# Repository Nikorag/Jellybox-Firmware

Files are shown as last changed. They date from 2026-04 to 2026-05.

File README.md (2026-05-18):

# Jellybox Firmware

<p align="center">
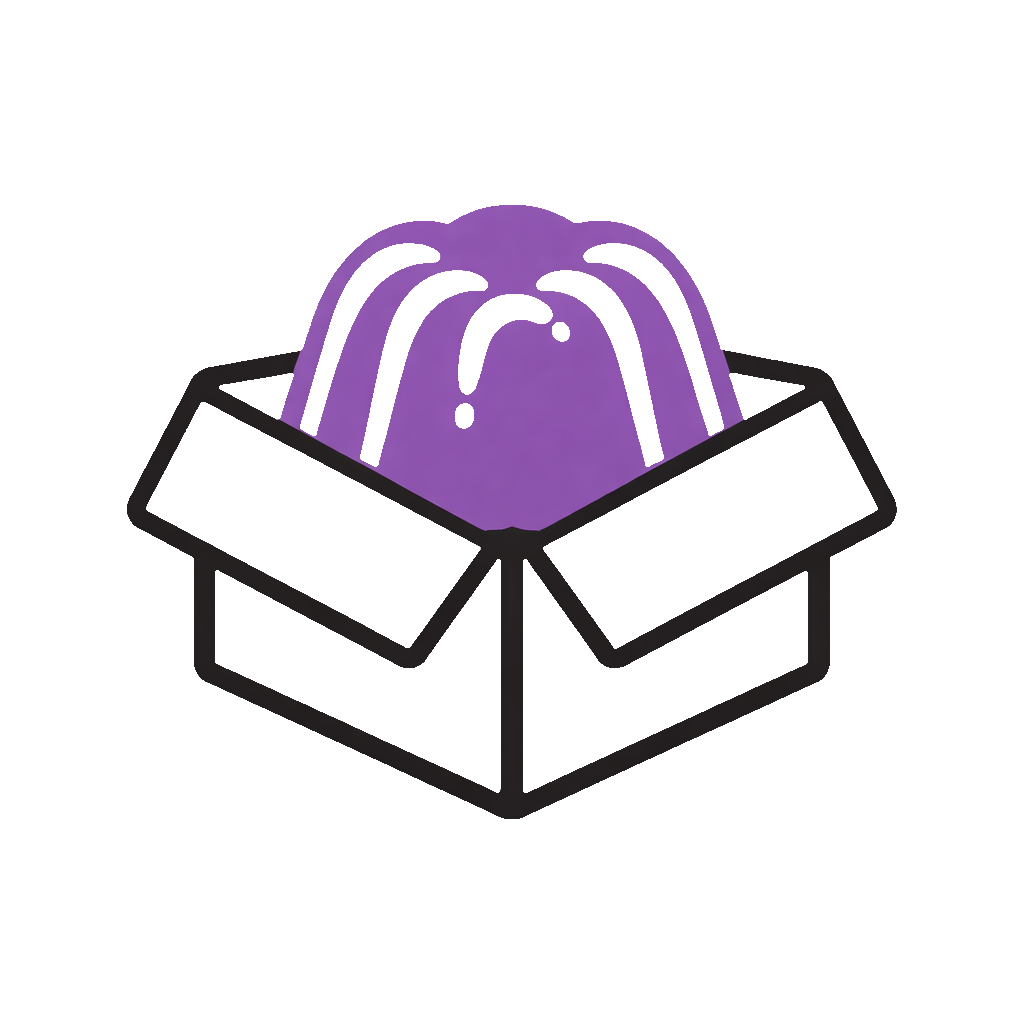
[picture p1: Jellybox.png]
Jellybox
  
</p>

ESP32 firmware for the Jellybox physical media player. Scan an RFID/NFC tag → instant playback on your Jellyfin server. No apps, no menus, no typing.

This firmware talks to a [Jellybox Server](https://github.com/Nikorag/Jellybox-Server) instance. You need a server account and a paired device before the firmware does anything useful.

---

## Hardware

| Component | Part |
|---|---|
| MCU | ESP32 Dev Module (any board with GPIO0 BOOT button) |
| NFC reader | PN532 breakout — I2C mode |
| Display | Waveshare 2.9" V2 B/W eInk (296 × 128) |
| LEDs | WS2812B NeoPixel ring — 16 pixels |
| Power | TP4056 with protection + boost converter (4-pad dual-function module) |
| Power switch | SPDT slide / toggle switch — wired in line between TP4056 `OUT+` and ESP32 `VIN` so the device can be turned off without disconnecting the battery |
| Battery | 18650 Li-Ion cell, 2500–3500 mAh |

See [WIRING.md](WIRING.md) for the full pinout, wiring diagrams, power budget, and component notes.

---

## Required Libraries

Install all of these via **Arduino IDE → Tools → Manage Libraries**:

| Library | Author | Min version |
|---|---|---|
| WiFiManager | tzapu | 2.0.17 |
| Adafruit NeoPixel | Adafruit | 1.12 |
| Adafruit PN532 | Adafruit | 1.3 |
| GxEPD2 | ZinggJM | 1.6 |
| Adafruit GFX Library | Adafruit | 1.11 |
| ArduinoJson | Benoit Blanchon | 7.0+ (uses v7 `JsonDocument` API — v6 needs code changes in `APIClient.h`) |

---

## Building and Flashing

1. Open `jellybox-firmware.ino` in Arduino IDE
2. Set board: **Tools → Board → ESP32 Dev Module**
3. Set partition scheme: **Tools → Partition Scheme → Minimal SPIFFS (1.9MB APP with OTA/190KB SPIFFS)**
   - The default 1.2 MB partition is too small for TLS + all libraries
   - This scheme provides two app partitions, which is required for OTA updates. If you flash with `Huge APP` instead, the device will work but will not be able to auto-update.
4. Select the correct port under **Tools → Port**
5. Click **Upload**

If the IDE shows "Connecting…" and stalls, hold the **BOOT button** on the ESP32 board until the upload begins.

> The TP4056 USB port is for battery charging only — it is not connected to the ESP32's UART. Use the ESP32 dev board's own USB port for flashing and serial monitoring.

---

## First-Time Setup

The pairing wizard in the Jellybox Server dashboard handles everything automatically. In brief:

1. Flash the firmware and power the device
2. The Jellybox splash screen appears, then "Connecting…"
3. The device broadcasts a WiFi AP: **`Jellybox-Setup`** (open, no password)
4. Open the Jellybox Server dashboard → **Devices → Pair New Device**
5. Follow the wizard — it detects the device portal automatically and submits your WiFi credentials, server URL, and API key directly to the device
6. The device reboots, connects to your network, and shows the device name on the eInk display

If you prefer to configure manually:
- Connect to the `Jellybox-Setup` network
- Navigate to `192.168.4.1` (captive portal opens automatically on most phones)
- Enter WiFi credentials, server URL, and API key, then submit

The portal times out after **180 seconds**. If it closes before you finish, the device restarts and broadcasts the AP again.

---

## Factory Reset

Hold the **BOOT button for 3 seconds** at any point while the device is running. The device clears all stored WiFi credentials and server config from NVS, then restarts into setup mode.

You can also trigger a factory reset during power-up: hold BOOT while connecting power.

---

## Over-the-Air Updates

OTA is **user-triggered from the dashboard**, not automatic. Devices never flash themselves the moment a new release lands — you decide when each Jellybox restarts.

**How it works**

1. Each release tag (e.g. `v0.1.0`) triggers the GitHub Actions workflow in `.github/workflows/release.yml`. The workflow builds the firmware with the version baked in (`-DFIRMWARE_VERSION="v0.1.0"`), publishes a release with the `.bin` plus a `manifest.json`.
2. The Jellybox Server fetches that manifest periodically. The device sends its currently-running version on every `GET /api/device/me` poll as a `?version=` query param.
3. The server only includes a `latestFirmware: { version, url }` block in the response **after the user clicks "Update firmware"** in the dashboard, which sets the device's `firmwareUpdatePending` flag.
4. When the device receives that block, it shows the "Updating firmware" screen, downloads the binary directly from GitHub, flashes it, and reboots into the new image.
5. After reboot the device reports the new version on its next poll. The server compares it to the manifest version and clears the pending flag automatically.

**Rollback safety**

Freshly flashed firmware is marked `PENDING_VERIFY` by the bootloader. The new image only commits itself once it has successfully reached the server (`[OTA] Marking current image valid` in the serial log). If the new firmware fails to connect, crashes, or hits a watchdog reset before that point, the bootloader rolls back to the previous working partition automatically. No bricked devices, no manual intervention.

**Local builds never auto-update**

Arduino IDE builds compile with `FIRMWARE_VERSION="dev"`. The OTA check short-circuits on `"dev"`, so a device flashed from your laptop will never overwrite your work-in-progress with a release build.

**Required partition scheme**

OTA needs two app partitions, which is why the build flag `Minimal SPIFFS (1.9MB APP with OTA/190KB SPIFFS)` is mandatory. Devices flashed with `Huge APP` will work but cannot auto-update — they'll need a USB reflash to pick up the OTA-capable partition table.

**Releasing a new version**

```bash
git tag v0.1.0
git push --tags
```

The workflow does the rest. Watch the Actions tab for the build, and the Releases tab for the published artifacts.

---

## LED States

The 16-pixel NeoPixel ring indicates device state at a glance.

| Colour / pattern | Meaning |
|---|---|
| Solid purple | Booting — shown during the blocking WiFi-connect phase in `setup()`, before the cooperative `loop()` takes over |
| Blue breathing | Ready to scan — idle, waiting for a tag |
| Cyan spin (comet) | Connecting — WiFi handshake or HTTP request in progress |
| Yellow spin (comet) | Bootstrapping — contacting the server |
| Purple breathing | Scan-capture mode — the next scan registers a tag, not play |
| Green flash | Success — playback started, or tag captured |
| Red flash | Error — check serial monitor for detail |
| Amber breathing | Unpaired — no config, or API key rejected (401) |
| Solid amber | Setup portal active — waiting for WiFi credentials (`loop()` is blocked, can't animate) |
| Fast white breathing | Charging — battery is charging via USB |
| Slow green breathing | Charged — battery is full |
| Violet spin (comet) | Updating firmware — OTA download in progress |

Charging states only show when the device is idle (READY). Scan-capture mode, errors, and success flashes take priority.

---

## eInk Display Screens

| Screen | When shown |
|---|---|
| Splash (logo + JELLYBOX) | Once at every boot |
| Connecting… | WiFi connecting with no known network |
| Connecting to `<SSID>` | After WiFi connects — shows the network name |
| Unpaired — connect to Jellybox-Setup | No config stored, or API key rejected |
| Logo / `<device name>` | Idle, waiting for a tag (intentionally indistinguishable from power-off — eInk persists) |
| `<device name>` / `[ SCAN MODE ]` | Scan-capture mode active |
| `<device name>` / Now playing: `<title>` | Tag scanned, playback started |
| Error: `<message>` | Something went wrong |
| Updating firmware / `<old> -> <new>` / Do not unplug | OTA update starting |
| Updating firmware / progress bar / `XX%` | OTA download in progress |
| Update failed / `<error>` | OTA download failed — device retries on next bootstrap |

---

## File Structure

| File | Purpose |
|---|---|
| `jellybox-firmware.ino` | `setup()` / `loop()` — state machine, WiFiManager, app entry point |
| `Config.h` | Pin definitions, NVS keys, timing constants |
| `LEDRing.h` | Non-blocking NeoPixel animations (breathing, spin, flash) |
| `EInkDisplay.h` | GxEPD2 screen layouts — all display states in one class |
| `JellyboxLogo.h` | 72×72 px PROGMEM bitmap for the splash / ready screens |
| `NFCReader.h` | PN532 I2C wrapper with UID debounce |
| `APIClient.h` | HTTPS client for `/api/device/me` and `/api/play` |
| `OTAUpdater.h` | OTA firmware download, install, and rollback-commit logic |
| `WIRING.md` | Full hardware wiring guide, pinout, and power budget |
| `.github/workflows/release.yml` | CI that builds firmware on `v*` tags and publishes a manifest for OTA |

---

## State Machine

```
                       ┌─────────────┐
          power on     │ UNCONFIGURED│ ◄── 401 from server
         ─────────────►│             │
                       └──────┬──────┘
                              │ WiFi + config saved
                              ▼
                       ┌─────────────┐
                       │ CONNECTING  │ WiFiManager autoConnect
                       └──────┬──────┘
                              │ connected
                              ▼
                       ┌──────────────┐
             ┌────────►│ BOOTSTRAPPING│ GET /api/device/me (every 30 s)
             │         └──────┬───────┘
             │                │ ok
             │       ┌────────┴────────┐
             │       │                 │
             │       ▼                 ▼
             │  ┌─────────┐     ┌───────────┐
             │  │  READY  │     │ SCAN_MODE │
             │  └────┬────┘     └─────┬─────┘
             │       │ NFC scan        │ NFC scan
             │       └────────┬────────┘
             │                │ POST /api/play
             └────────────────┘ (re-bootstrap every 30 s)

   BOOTSTRAPPING ──► UPDATING ──► reboot into new firmware
                       │ (only if latestFirmware.version != FIRMWARE_VERSION)
                       └► back to BOOTSTRAPPING on download failure
```

---

## API Interactions

The firmware makes two HTTPS calls to the server:

**`GET /api/device/me`** — called at boot and every 30 seconds  
Authenticated with `Authorization: Bearer <apiKey>`. Returns:
```json
{
  "name": "Living Room Box",
  "scanMode": false,
  "latestFirmware": {
    "version": "v0.1.0",
    "url": "https://github.com/.../jellybox-firmware-v0.1.0.bin"
  }
}
```
A `401` response sets the device to UNPAIRED state. Other errors are retried on the next interval. The `latestFirmware` block is only present when the user has flagged the device for an update in the dashboard — otherwise it's omitted and the firmware treats that as "no update available". See the [OTA section](#over-the-air-updates) for the full update flow.

**`POST /api/play`** — called when a tag is scanned  
```json
{ "tagId": "A1B2C3D4" }
```
Returns either:
```json
{ "success": true, "content": "The Dark Knight" }
{ "captured": true }
{ "error": "Tag not assigned" }
```

TLS certificates are not verified on-device (`setInsecure()`). The API key is the shared secret; verifying the server cert would require bundling a CA store, which is impractical for a battery-powered device pointing at a self-hosted server.

---

## Customisation

### Changing the eInk panel

Edit the top of `EInkDisplay.h`. The include and class alias are the only two lines to change:

```cpp
// Example: Waveshare 2.13" V3 (250×122)
#include <epd/GxEPD2_213_BN.h>
using Panel = GxEPD2_BW<GxEPD2_213_BN, GxEPD2_213_BN::HEIGHT>;
```

Adjust `EINK_W`, `EINK_H`, and `EINK_MARGIN_R` to match the new panel's pixel dimensions and dead zone.

### Changing the NeoPixel count or pin

Edit `Config.h`:
```cpp
#define PIN_NEOPIXEL   27
#define NEOPIXEL_COUNT 16
```

### Adjusting poll intervals

Also in `Config.h`:
```cpp
#define BOOTSTRAP_INTERVAL_MS  30000UL  // server poll — every 30 s
#define SCAN_DEBOUNCE_MS        3000UL  // ignore same UID for 3 s
#define FACTORY_RESET_HOLD_MS   3000UL  // hold BOOT 3 s to reset
```

---

## Stored Configuration (NVS)

Config is stored in the ESP32's Non-Volatile Storage under the `jellybox` namespace. The partition scheme change (`Minimal SPIFFS`) does not affect NVS — it is a separate partition and survives reflashing.

| Key | Value |
|---|---|
| `serverUrl` | Full server URL, e.g. `https://jellybox.example.com` |
| `apiKey` | Device API key, e.g. `jb_abc123…` |

WiFi credentials are stored separately by the ESP32 WiFi stack and erased by `WiFi.disconnect(true, true)` during a factory reset.

---

## Serial Monitor

Connect at **115200 baud**. All state transitions, NFC scans, API calls, and errors are logged with prefixed tags:

```
[NFC]    Tag: A1B2C3D4
[API]    POST /api/play → 200
[Play]   Playing: The Dark Knight
[Boot]   Device: Living Room Box scanMode=0
[Charge] charging
[Reset]  BOOT held...
[OTA]    Update available: v0.0.3 -> v0.1.0
[OTA]    Marking current image valid (was pending verify)
```

The boot banner also reports the running firmware version, e.g. `=== Jellybox starting (firmware v0.1.0) ===` (or `firmware dev` for local builds).

---

## License

MIT

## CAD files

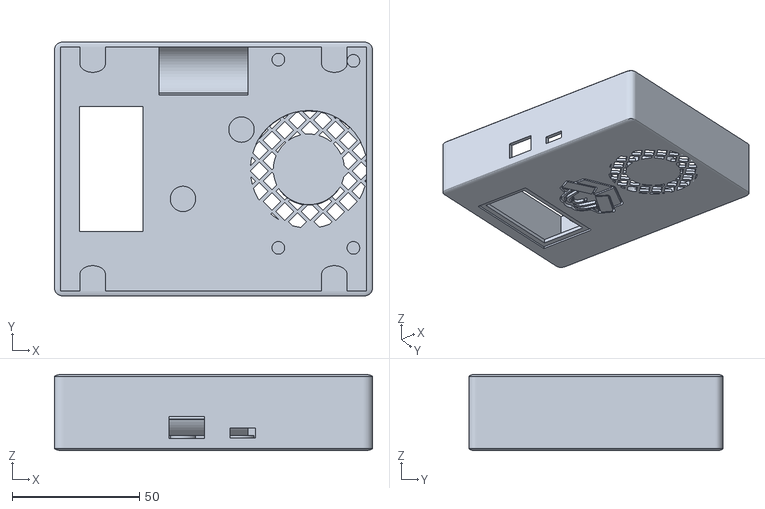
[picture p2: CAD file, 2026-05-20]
models/Jellybox Case.stl
125.0 x 100.0 x 30.0

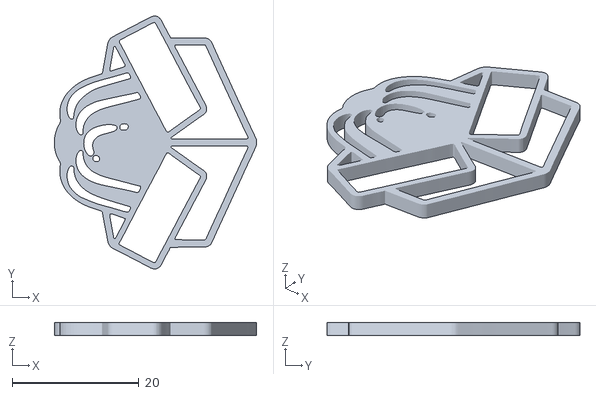
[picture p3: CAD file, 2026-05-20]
models/Jellybox Logo.stl
32.0 x 40.0 x 2.00

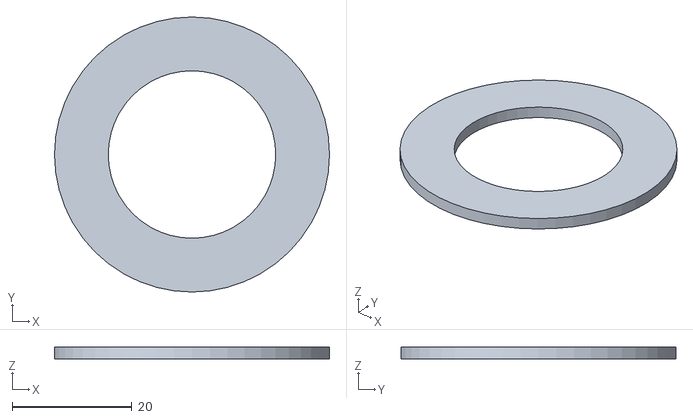
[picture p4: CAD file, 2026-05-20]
models/Jellybox Ring.stl
46.0 x 46.0 x 2.00

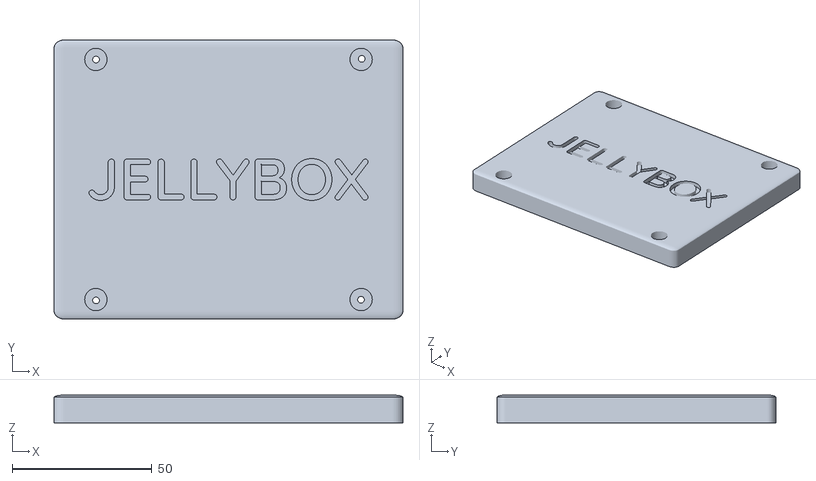
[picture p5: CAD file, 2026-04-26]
models/Jellybox Lid.stl
125.0 x 100.0 x 10.00

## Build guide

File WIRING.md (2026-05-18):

# Jellybox Hardware Wiring

Hardware reference for assembling a Jellybox device.
Signal logic runs at **3.3 V**. The TP4056 module provides a regulated **5 V** rail that
powers everything; the ESP32's onboard LDO steps that down to 3.3 V for the PN532 and eInk.

---

## Components

| Component | Part |
|---|---|
| MCU | ESP32 Dev Module (any board with GPIO0 BOOT button) |
| Power | 5 V / 1 A TP4056 with protection + boost converter (dual-function, 4-pad module) |
| Power switch | SPDT slide or toggle switch (any small switch rated ≥ 1 A) |
| Battery | 18650 Li-Ion cell — see battery selection note below |
| NFC reader | PN532 breakout (I2C mode) |
| Display | Waveshare 2.9" V2 B/W eInk (296 × 128) |
| LEDs | WS2812B NeoPixel ring — 16 pixels |
| Reset button | On-board BOOT button (GPIO0) |

---

## Battery Selection

Any genuine 18650 Li-Ion cell. The TP4056 charges at ~1 A, so aim for at least 1500 mAh
(keeping charge rate ≤ 0.66 C). A **2500–3500 mAh** cell is ideal.

| Cell | Capacity | Notes |
|---|---|---|
| Samsung 25R | 2500 mAh | Widely available, reliable |
| LG HG2 | 3000 mAh | Good capacity/current balance |
| Molicel P26A | 2600 mAh | Excellent quality |

Buy from a reputable supplier. Avoid unbranded cells claiming ≥ 5000 mAh — 18650 cells
physically cannot hold more than ~3600 mAh; anything higher is a false rating.

**Estimated runtime** at typical idle (WiFi connected, LED breathing, no active scans):
~120–150 mA average draw → **16–23 hours** from a 2500 mAh cell.

---

## Pin Assignment

| Signal | ESP32 GPIO | Connected to |
|---|---|---|
| I2C SDA | 21 (default) | PN532 SDA |
| I2C SCL | 22 (default) | PN532 SCL |
| PN532 IRQ | 25 | PN532 IRQ |
| PN532 RST | 26 | PN532 RST / RSTO |
| SPI MOSI | 23 (VSPI default) | eInk DIN |
| SPI SCK | 18 (VSPI default) | eInk CLK |
| eInk CS | 5¹ | eInk CS |
| eInk DC | 17 | eInk DC |
| eInk RST | 16 | eInk RST |
| eInk BUSY | 4 | eInk BUSY |
| NeoPixel DATA | 27 | Ring DATA IN (via 470 Ω) |
| TP4056 CHRG | 32 | Red LED cathode on TP4056 module |
| TP4056 STDBY | 33 | Blue LED cathode on TP4056 module |
| Factory reset | 0 | BOOT button (on-board) |

> ¹ GPIO5 is an ESP32 boot-mode strapping pin. The eInk CS line idles HIGH (SPI CS is
> active-low), so it does not affect boot behaviour. If you ever see unexpected boot
> failures, probe GPIO5 at power-on.

---

## 1 — TP4056 Power Module

The module has **4 solder pads** and a single USB port (charging input):

| Pad label | Purpose |
|---|---|
| `OUT+` | 5 V regulated output — connect to ESP32 VIN and NeoPixel PWR |
| `OUT−` | GND — connect to common ground |
| `B+` | Battery positive — connect to 18650 cell + terminal |
| `B−` | Battery negative — connect to 18650 cell − terminal |

```
USB (wall/PC)
     │
 [TP4056 module]
  ┌──┴────────────────┐
  │  B+  ←→  18650 +  │
  │  B−  ←→  18650 −  │
  │                   │
  │  OUT+ ──→ [SPDT switch] ──→ 5V rail (ESP32 VIN, NeoPixel PWR)
  │  OUT− ──────────────────────→ GND
  └───────────────────┘
```

**Power switch:** wire an **SPDT slide or toggle switch** in series between TP4056 `OUT+` and
the ESP32 `VIN` pin (the same node that feeds NeoPixel `PWR`). Flipping the switch off
completely disconnects the 5 V rail so the device draws no power from the cell — the only
correct way to "turn the Jellybox off" between uses, since the firmware has no sleep mode yet.

> **Switch the OUT+ side, not B+.** Wiring the switch between the cell and the TP4056 input
> would also disconnect the charger, meaning the device couldn't charge over USB while
> switched off. With the switch on `OUT+`, USB charging still works with the device powered
> down.

**Simultaneous charge and run:** this module supports pass-through — when the switch is on,
the device can run from the 5 V output while USB is connected and the battery is charging.

**Current headroom:** total worst-case draw is ~470 mA (see power budget below). The module is
rated 1 A output, leaving ~530 mA headroom. Simultaneous WiFi TX + NFC field + full LED is
unlikely in practice; average draw in normal use is well under 200 mA.

---

## 2 — TP4056 Charging Indicator (optional)

The firmware uses the NeoPixel ring to indicate charge state. This requires tapping the
TP4056's two status outputs: `CHRG` (active while charging) and `STDBY` (active when full).
Both are open-drain, active-LOW signals.

### Where to solder

Your module has two small indicator LEDs on the PCB (typically red = charging, blue = full).
Solder fine wire to the **cathode** of each LED — that pad connects directly to the TP4056
status pin. The cathode is the shorter leg, or the leg on the flat/marked side of the LED.

Use a fine-tipped iron and thin wire (~28 AWG). The pads are small; work quickly to avoid
lifting them.

```
TP4056 module (LED cathode pads)    ESP32
────────────────────────────────────────────
Red LED cathode  (CHRG)   →   GPIO 32   (INPUT_PULLUP)
Blue LED cathode (STDBY)  →   GPIO 33   (INPUT_PULLUP)
```

### Why no voltage divider is needed

The ESP32's internal pull-up (45 kΩ to 3.3 V) clamps the floating-high state to 3.3 V.
The on-board LED's series resistor (~1 kΩ) + forward voltage (~2 V) prevents the 5 V rail
from forward-biasing the LED in the direction of the GPIO, so no 5 V reaches the pin.
When the TP4056 pulls the output LOW, the GPIO reads 0 V regardless of the pull-up.

### LED behaviour

| Ring animation | Meaning |
|---|---|
| Fast white breathing (~2.4 s) | Battery charging |
| Slow green breathing (~6 s) | Battery full |
| Blue breathing (normal IDLE) | On battery, not connected to charger |

Charging states only show when the device is in READY state. SCAN_MODE, UNPAIRED, and
transient flashes (SUCCESS / ERROR) take priority.

---

## 3 — PN532 NFC Reader (I2C)

### Set I2C mode first

The PN532 supports I2C, SPI, and UART. **You must select I2C before wiring.**

- **Adafruit breakout:** flip the two DIP switches — `SW1 = ON`, `SW2 = OFF`
- **Other breakouts:** consult the board's datasheet for the I2C solder-jumper or switch positions

### Connections

```
PN532 breakout       ESP32
──────────────────────────────
VCC           →   3.3V
GND           →   GND
SDA           →   GPIO 21
SCL           →   GPIO 22
IRQ           →   GPIO 25
RST (RSTO)    →   GPIO 26
```

> **VCC note:** connect to the ESP32's 3V3 pin. Most PN532 breakout boards accept 3.3 V directly
> on their logic/VCC pin and run reliably at that voltage.

### Pull-ups

The Adafruit PN532 breakout includes on-board 4.7 kΩ pull-ups on SDA and SCL — no external
resistors needed. If using a bare PN532 module without on-board pull-ups, add 4.7 kΩ resistors
from SDA → 3.3 V and SCL → 3.3 V.

---

## 4 — Waveshare 2.9" V2 eInk Display (SPI)

Pin labels vary by module revision. Common label sets and their mappings:

| Signal | Variant A labels | Variant B labels |
|---|---|---|
| Power | VCC | VCC |
| Ground | GND | GND |
| Data (MOSI) | DIN | SDA |
| Clock (SCK) | CLK | SCL |
| Chip select | CS | CS |
| Data/command | DC | DC |
| Reset | RST | RES |
| Busy | BUSY | BUSY |

MISO is not connected — the panel is write-only.

```
Your module    Signal        ESP32
──────────────────────────────────
VCC        →  3.3V
GND        →  GND
SDA / DIN  →  GPIO 23   (MOSI)
SCL / CLK  →  GPIO 18   (SCK)
CS         →  GPIO  5
DC         →  GPIO 17
RES / RST  →  GPIO 16
BUSY       →  GPIO  4
```

GxEPD2 initialises the SPI bus internally — no `SPI.begin()` call is needed in the sketch.

---

## 5 — WS2812B NeoPixel Ring (16 pixels)

```
NeoPixel ring        Power / ESP32
────────────────────────────────────
PWR (5V)      →   TP4056 OUT+  (5 V rail — not the ESP32 5V pin)
GND           →   GND
DATA IN       →   GPIO 27  (via 300–470 Ω series resistor)
```

**Why TP4056 OUT+ directly?** The ESP32 dev board's 5 V / VBUS pin is only live when USB is
connected. When running on battery alone that pin is dead. Tapping the 5 V rail from the
TP4056 output ensures the ring is powered in both USB and battery modes.

**Series resistor:** place a 300–470 Ω resistor on the data line between GPIO27 and the
ring's DATA IN pad. It suppresses ringing and protects the first pixel's input driver.

---

## 6 — Factory Reset Button

The BOOT button is already wired to GPIO0 on most ESP32 dev boards with an on-board pull-up.
No additional wiring is needed.

If building a custom PCB, wire a momentary pushbutton between GPIO0 and GND. The firmware
configures `INPUT_PULLUP` in software, so no external pull-up is required.

**To factory reset:** hold the BOOT button for 3 seconds on power-up. The device clears its
NVS config and stored WiFi credentials, then restarts into setup mode.

---

## 7 — Power Budget

| Subsystem | Typical draw |
|---|---|
| ESP32 active + WiFi TX | ~200 mA peak |
| WS2812B ring (brightness 80/255) | ~150 mA |
| PN532 during RF field | ~100 mA peak |
| eInk during refresh | ~20 mA |
| **Total worst-case** | **~470 mA** |
| **TP4056 output rating** | **1000 mA** |
| **Headroom** | **~530 mA** |

All peaks are brief and non-overlapping in normal use. Average idle draw (WiFi connected,
LED breathing, waiting for a scan) is approximately **120–150 mA**.

The TP4056 module's onboard LDO is not in this path — the boost converter output feeds
ESP32 VIN directly. The ESP32's onboard AMS1117 (3.3 V, 800 mA) is fed clean 5 V and
supplies the PN532 and eInk from its 3V3 pin.

---

## 8 — Full Wiring Diagram

```
  [USB charger]                    [18650 cell]
       │                            │       │
       │          ┌─────────────────┤ B+  B−├──┐
       └──────────┤ USB    TP4056              │ │
                  │  5V boost module           │ │
                  │         OUT+ ──[SPDT sw]───┼─┼──── 5V rail
                  │         OUT− ──────────────┼─┼──── GND rail
                  └────────────────────────────┘ │
                                                  │ (battery ground)
                                                  ▼

  5V rail ────────────────────────────────────────────────┐
                                                          │
                 ┌──────────────────────────────────────┐ │
    NeoPixel PWR─┤ VIN (→ AMS1117 → 3V3)               │ │
                 │                                       │ │
 [NeoPixel]──470Ω│ GPIO27              GPIO21 ───────────│─┼── SDA ──[PN532]
 [eInk RES/RST]──│ GPIO16              GPIO22 ───────────│─┼── SCL ──[PN532]
 [eInk DC]───────│ GPIO17              GPIO25 ───────────│─┼── IRQ ──[PN532]
 [eInk BUSY]─────│ GPIO 4              GPIO26 ───────────│─┼── RST ──[PN532]
 [eInk CS]───────│ GPIO 5                                │ │
 [eInk SCL/SCK]──│ GPIO18              GPIO 0 ───────────│─┼── BOOT button
 [eInk SDA/DIN]──│ GPIO23                                │ │
                 │                          3V3 ─────────│─┼── PN532 VCC
                 │                          3V3 ─────────│─┼── eInk VCC
                 │                          GND ─────────│─┼── all GND
                 └──────────────────────────────────────┘ │
                                                          │
  GND rail ────────────────────────────────────────────── ┘
```

---

## 9 — First Boot

1. Flash the firmware via Arduino IDE (**Board: ESP32 Dev Module**) with USB connected
2. Disconnect USB. The device now runs from the battery (LED will light)
3. On first boot it broadcasts a WiFi AP: **`Jellybox-Setup`** (open, no password)
4. Connect to it — a captive portal opens automatically (or navigate to `192.168.4.1`)
5. Enter your WiFi credentials, the server URL, and the device API key from the dashboard
6. Submit — the device reboots, connects, and shows the device name on the eInk display

If the portal times out (180 s default) without a submission, the device restarts and
broadcasts the AP again.

> **Flashing note:** flashing via Arduino IDE requires USB. The TP4056's USB port is for
> charging only — it is not connected to the ESP32's USB/UART. Use the ESP32 dev board's own
> USB port for flashing and serial monitoring.

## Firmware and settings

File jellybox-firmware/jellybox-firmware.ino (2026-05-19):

/**
 * Jellybox Firmware
 *
 * ESP32 companion device for the Jellybox Server SaaS.
 * Scans RFID/NFC tags → POST /api/play → Jellyfin playback.
 *
 * Required Arduino libraries (install via Library Manager):
 *   - WiFiManager         by tzapu          (v2.0.17+)
 *   - Adafruit NeoPixel   by Adafruit       (v1.12+)
 *   - Adafruit PN532      by Adafruit       (v1.3+)
 *   - GxEPD2              by ZinggJM        (v1.6+)
 *   - Adafruit GFX Library by Adafruit      (v1.11+)
 *   - ArduinoJson         by Benoit Blanchon (v7+ or v6 — see APIClient.h)
 *
 * Board: ESP32 Dev Module (Arduino ESP32 core v2.x or v3.x)
 */

#include <WiFi.h>
#include <WiFiManager.h>
#include <Preferences.h>

#include "Config.h"
#include "LEDRing.h"
#ifdef JELLYBOX_DISPLAY_TFT
  #include "TFTDisplay.h"
#else
  #include "EInkDisplay.h"
#endif
#include "NFCReader.h"
#include "APIClient.h"
#include "OTAUpdater.h"
#include "UDPLogger.h"
#ifdef JELLYBOX_HAS_AUDIO
  #include "AudioFeedback.h"
#endif
#ifdef JELLYBOX_HAS_VOLUME_DIAL
  #include "VolumeControl.h"
#endif

LEDRing     led;
#ifdef JELLYBOX_DISPLAY_TFT
TFTDisplay  eink;   // variable name unchanged so existing call sites work as-is
#else
EInkDisplay eink;
#endif
NFCReader   nfc;
APIClient   api;
UDPLogger   ulog;
Preferences prefs;
#ifdef JELLYBOX_HAS_AUDIO
AudioFeedback audio;
#endif
#ifdef JELLYBOX_HAS_VOLUME_DIAL
VolumeControl volume;
#endif

// Returns the current audio gain (0.0–1.0). Uses the volume dial when
// compiled in, otherwise a sensible fixed level so the speaker isn't
// deafening on boards without a dial.
static inline float audioGain() {
#ifdef JELLYBOX_HAS_VOLUME_DIAL
  return volume.gain();
#else
  return 0.6f;
#endif
}

DeviceConfig cfg;

// Diagnostic state for the UDP heartbeat. Tracks NFC liveness from the
// main loop's perspective — readUID() returning "" looks the same whether
// the PN532 is dead, the I2C bus is stuck, or there genuinely isn't a tag.
unsigned long lastHeartbeat       = 0;
unsigned long emptyReadsInWindow  = 0;
unsigned long lastSuccessfulRead  = 0;
String        lastSuccessfulUID   = "";

enum class AppState {
  UNCONFIGURED,
  CONNECTING,
  BOOTSTRAPPING,
  READY,
  SCAN_MODE,
  UPDATING,
};
AppState appState = AppState::UNCONFIGURED;

String        deviceName   = "";
bool          nfcReady     = false;
unsigned long lastBootstrap = 0;

unsigned long bootBtnStart = 0;
bool          bootBtnHeld  = false;

WiFiManagerParameter* wm_serverUrl = nullptr;
WiFiManagerParameter* wm_apiKey    = nullptr;

void loadConfig() {
  prefs.begin(NVS_NAMESPACE, true);
  cfg.serverUrl = prefs.getString(NVS_KEY_SERVER, "");
  cfg.apiKey    = prefs.getString(NVS_KEY_APIKEY,  "");
  prefs.end();
  if (cfg.serverUrl.endsWith("/"))
    cfg.serverUrl = cfg.serverUrl.substring(0, cfg.serverUrl.length() - 1);
}

void saveConfig(const String& serverUrl, const String& apiKey) {
  String su = serverUrl;
  if (su.endsWith("/")) su = su.substring(0, su.length() - 1);
  prefs.begin(NVS_NAMESPACE, false);
  prefs.putString(NVS_KEY_SERVER, su);
  prefs.putString(NVS_KEY_APIKEY,  apiKey);
  prefs.end();
  Serial.println("[Config] Saved — server: " + su);
}

void factoryReset() {
  Serial.println("[Config] Factory reset!");
  prefs.begin(NVS_NAMESPACE, false);
  prefs.clear();
  prefs.end();
  WiFi.disconnect(true, true);
  delay(300);
  ESP.restart();
}

void onPortalSave() {
  if (!wm_serverUrl || !wm_apiKey) return;
  String su = String(wm_serverUrl->getValue());
  String ak = String(wm_apiKey->getValue());
  su.trim(); ak.trim();
  saveConfig(su, ak);
  cfg.serverUrl = su;
  cfg.apiKey    = ak;
}

void startWiFi(bool forcePortal) {
  WiFiManager wm;
  wm.setConnectTimeout(20);
  wm.setConfigPortalTimeout(WIFI_TIMEOUT_S);
  wm.setSaveParamsCallback(onPortalSave);
  wm.setTitle("Jellybox Setup");
  wm.setShowInfoUpdate(false);
  wm_serverUrl = new WiFiManagerParameter("server", "Server URL", cfg.serverUrl.c_str(), 128, " placeholder=\"https://jellybox.example.com\"");
  wm_apiKey    = new WiFiManagerParameter("apikey",  "API Key",    cfg.apiKey.c_str(),    80,  " placeholder=\"jb_...\"");
  wm.addParameter(wm_serverUrl);
  wm.addParameter(wm_apiKey);
  wm.setWebServerCallback([&]() {
    wm.server->on("/hotspot-detect.html", HTTP_GET, [&]() {
      wm.server->send(200, "text/html", "<HTML><HEAD><TITLE>Success</TITLE></HEAD><BODY>Success</BODY></HTML>");
    });
    wm.server->on("/generate_204", HTTP_GET, [&]() {
      wm.server->send(204, "text/plain", "");
    });
  });
  bool connected = forcePortal
    ? (eink.showUnpaired(), led.setState(LEDState::SETUP_PORTAL), led.setBaseState(LEDState::UNPAIRED), led.update(), wm.startConfigPortal(WIFI_AP_NAME, WIFI_AP_PASSWORD))
    : wm.autoConnect(WIFI_AP_NAME, WIFI_AP_PASSWORD);
  delete wm_serverUrl; wm_serverUrl = nullptr;
  delete wm_apiKey;    wm_apiKey    = nullptr;
  if (!connected) { Serial.println("[WiFi] Failed — restarting"); delay(500); ESP.restart(); }
  eink.showConnecting(WiFi.SSID());
  Serial.println("[WiFi] Connected to " + WiFi.SSID() + " — IP: " + WiFi.localIP().toString());
}

void doBootstrap() {
  unsigned long t0 = millis();
  ulog.logf("BOOT bootstrap_start heap=%u maxAlloc=%u",
    (unsigned)ESP.getFreeHeap(), (unsigned)ESP.getMaxAllocHeap());
  led.setState(LEDState::BOOTSTRAPPING);
  led.setBaseState(LEDState::BOOTSTRAPPING);
  api.configure(cfg.serverUrl, cfg.apiKey);
  BootstrapResult res = api.bootstrap();
  lastBootstrap = millis();
  if (!res.ok) {
    ulog.logf("BOOT bootstrap_fail http=%d took=%lums heap=%u",
      res.httpCode, millis() - t0, (unsigned)ESP.getFreeHeap());
    if (res.httpCode == 401) {
      Serial.println("[Boot] 401 — invalid API key");
      eink.showUnpaired(); led.setState(LEDState::ERROR); led.setBaseState(LEDState::UNPAIRED);
      appState = AppState::UNCONFIGURED;
    } else {
      Serial.printf("[Boot] Error HTTP %d — retrying later\n", res.httpCode);
      if (WiFi.status() != WL_CONNECTED) WiFi.reconnect();
      led.setState(LEDState::ERROR); led.setBaseState(LEDState::IDLE);
      if (deviceName.isEmpty()) eink.showConnecting();
      appState = AppState::READY;
    }
    return;
  }
  deviceName = res.name;
  Serial.println("[Boot] Device: " + deviceName + " scanMode=" + String(res.scanMode));

  // First successful bootstrap proves the running firmware can talk to the
  // network and the server — commit the partition so the bootloader doesn't
  // roll it back on next reset. No-op on subsequent boots.
  static bool firstBootstrapDone = false;
  if (!firstBootstrapDone) {
    firstBootstrapDone = true;
    OTAUpdater::markCurrentAppValid();
  }

  // Server-driven OTA. If an update is available, this either reboots into
  // the new firmware (success) or falls through and we resume normal flow
  // — the same update will be retried on the next bootstrap.
  if (OTAUpdater::isUpdateAvailable(res.latestFirmwareVersion)) {
    Serial.printf("[OTA] Update available: %s -> %s\n",
      FIRMWARE_VERSION, res.latestFirmwareVersion.c_str());
    appState = AppState::UPDATING;
    led.setState(LEDState::UPDATING);
    led.setBaseState(LEDState::UPDATING);
    eink.showUpdating(FIRMWARE_VERSION, res.latestFirmwareVersion);
    if (!OTAUpdater::performUpdate(res.latestFirmwareUrl)) {
      eink.showUpdateFailed("Update failed - will retry");
      unsigned long wait = millis();
      while (millis() - wait < 3000) { led.update(); checkFactoryReset(); delay(10); }
    }
    // On success the device has rebooted and we never get here.
  }

  if (res.scanMode) {
    appState = AppState::SCAN_MODE;
    led.setBaseState(LEDState::SCAN_MODE); led.setState(LEDState::SCAN_MODE);
    eink.showScanMode(deviceName);
  } else {
    appState = AppState::READY;
    led.setBaseState(LEDState::IDLE); led.setState(LEDState::IDLE);
    eink.showReady(deviceName);
  }
  // HTTPS handshake + eInk full-window refresh can wedge the PN532's
  // passive-target state machine while leaving I2C alive — re-arm before
  // returning so the next readUID() actually detects tags.
  if (nfcReady) nfc.rearm();
  ulog.logf("BOOT bootstrap_ok scanMode=%d took=%lums heap=%u maxAlloc=%u pn532=0x%08x",
    (int)res.scanMode, millis() - t0,
    (unsigned)ESP.getFreeHeap(), (unsigned)ESP.getMaxAllocHeap(),
    (unsigned)(nfcReady ? nfc.firmwareVersion() : 0));
}

void handleScan(const String& uid) {
  unsigned long t0 = millis();
  ulog.logf("SCAN start uid=%s heap=%u", uid.c_str(), (unsigned)ESP.getFreeHeap());
  led.setState(LEDState::CONNECTING); led.update();
  PlayResult res = api.play(uid);
  if (res.ok) {
    led.setState(LEDState::SUCCESS);
    if (res.captured) {
      Serial.println("[Play] Tag captured: " + uid);
      eink.showReady(deviceName); lastBootstrap = 0;
#ifdef JELLYBOX_HAS_AUDIO
      audio.playImported(audioGain());
#endif
    } else {
      Serial.println("[Play] Playing: " + res.content);
      eink.showLastPlayed(deviceName, res.content);
#ifdef JELLYBOX_HAS_AUDIO
      audio.playSuccess(audioGain());
#endif
    }
  } else {
    Serial.println("[Play] Error: " + res.error);
    led.setState(LEDState::ERROR);
    eink.showError(res.error.isEmpty() ? "Play failed" : res.error);
#ifdef JELLYBOX_HAS_AUDIO
    audio.playError(audioGain());
#endif
    unsigned long wait = millis();
    while (millis() - wait < 3000) { led.update(); checkFactoryReset(); delay(10); }
    appState == AppState::SCAN_MODE ? eink.showScanMode(deviceName) : eink.showReady(deviceName);
  }
  ulog.logf("SCAN end ok=%d captured=%d http=%d content='%s' err='%s' took=%lums heap=%u",
    (int)res.ok, (int)res.captured, res.httpCode,
    res.content.c_str(), res.error.c_str(), millis() - t0,
    (unsigned)ESP.getFreeHeap());
}

void checkFactoryReset() {
  if (digitalRead(PIN_FACTORY_RESET) == LOW) {
    if (!bootBtnHeld) { bootBtnHeld = true; bootBtnStart = millis(); Serial.println("[Reset] BOOT held..."); }
    else if (millis() - bootBtnStart > FACTORY_RESET_HOLD_MS) {
      led.setState(LEDState::ERROR); led.update(); eink.showUnpaired(); factoryReset();
    }
  } else { bootBtnHeld = false; }
}

void setup() {
  Serial.begin(115200); delay(100);
  Serial.printf("\n\n=== Jellybox starting %s ===\n", FIRMWARE_VERSION);
  pinMode(PIN_FACTORY_RESET, INPUT_PULLUP);
  led.begin(); led.setState(LEDState::BOOTING); led.update();
#ifdef JELLYBOX_DISPLAY_EINK
  // Pre-set eInk control pins as outputs at idle level so GxEPD2's init()
  // doesn't trip the "digitalWrite before pinMode" warning on ESP32 core 3.x.
  pinMode(PIN_EINK_CS,  OUTPUT); digitalWrite(PIN_EINK_CS,  HIGH);
  pinMode(PIN_EINK_DC,  OUTPUT); digitalWrite(PIN_EINK_DC,  HIGH);
  pinMode(PIN_EINK_RST, OUTPUT); digitalWrite(PIN_EINK_RST, HIGH);
#endif
#ifdef JELLYBOX_DISPLAY_TFT
  pinMode(PIN_TFT_CS,  OUTPUT); digitalWrite(PIN_TFT_CS,  HIGH);
  pinMode(PIN_TFT_DC,  OUTPUT); digitalWrite(PIN_TFT_DC,  HIGH);
  pinMode(PIN_TFT_RST, OUTPUT); digitalWrite(PIN_TFT_RST, HIGH);
#endif
  eink.begin(); eink.showSplash(); eink.showConnecting();
#ifdef JELLYBOX_HAS_VOLUME_DIAL
  volume.begin();
#endif
  loadConfig();
  { unsigned long h = millis();
    while (digitalRead(PIN_FACTORY_RESET) == LOW) {
      led.update();
      if (millis() - h > FACTORY_RESET_HOLD_MS) { Serial.println("[Reset] Factory reset on boot"); led.setState(LEDState::ERROR); led.update(); eink.showUnpaired(); factoryReset(); }
      delay(10);
    }
  }
  nfcReady = nfc.begin();
  if (!nfcReady) Serial.println("[NFC] Reader not found — NFC disabled");
  bool needPortal = cfg.serverUrl.isEmpty() || cfg.apiKey.isEmpty();
  startWiFi(needPortal);
  ulog.begin(UDP_LOG_HOST, UDP_LOG_PORT);
#ifdef JELLYBOX_HAS_AUDIO
  audio.begin();
#endif
  ulog.logf("BOOT fw=%s ip=%s ssid=%s heap=%u nfc=%d pn532=0x%08x",
    FIRMWARE_VERSION, WiFi.localIP().toString().c_str(),
    WiFi.SSID().c_str(), (unsigned)ESP.getFreeHeap(),
    (int)nfcReady, (unsigned)(nfcReady ? nfc.firmwareVersion() : 0));
  loadConfig();
  if (cfg.serverUrl.isEmpty() || cfg.apiKey.isEmpty()) {
    Serial.println("[Config] Incomplete — waiting for reset");
    eink.showUnpaired(); led.setBaseState(LEDState::UNPAIRED); led.setState(LEDState::UNPAIRED);
    while (true) { led.update(); checkFactoryReset(); delay(10); }
  }
  doBootstrap();
}

void loop() {
  checkFactoryReset();
  led.update();
#ifdef JELLYBOX_HAS_VOLUME_DIAL
  volume.update();
#endif
  if (millis() - lastBootstrap > BOOTSTRAP_INTERVAL_MS) { doBootstrap(); return; }
  if (nfcReady && (appState == AppState::READY || appState == AppState::SCAN_MODE)) {
    String uid = nfc.readUID();
    if (uid.length() > 0) {
      lastSuccessfulRead = millis();
      lastSuccessfulUID  = uid;
      handleScan(uid);
      // handleScan ran HTTPS + 1–2 eInk full refreshes; same wedge risk
      // as doBootstrap, same fix.
      nfc.rearm();
    } else {
      emptyReadsInWindow++;
    }
  }

  // pn532 firmware-version probe distinguishes "I2C/chip dead" from
  // "chip alive, RF detection broken" — same UDP packet either way.
  if (millis() - lastHeartbeat > HEARTBEAT_INTERVAL_MS) {
    lastHeartbeat = millis();
    uint32_t fw = nfcReady ? nfc.firmwareVersion() : 0;
    unsigned long ageS = (lastSuccessfulRead == 0)
      ? 0 : (millis() - lastSuccessfulRead) / 1000;
    ulog.logf("HB state=%d heap=%u maxAlloc=%u empty=%lu lastUID=%s ageS=%lu pn532=0x%08x wifi=%d",
      (int)appState, (unsigned)ESP.getFreeHeap(), (unsigned)ESP.getMaxAllocHeap(),
      emptyReadsInWindow,
      lastSuccessfulUID.length() ? lastSuccessfulUID.c_str() : "-",
      ageS, (unsigned)fw, (int)WiFi.status());
    emptyReadsInWindow = 0;
    // Preemptive rearm every heartbeat. The chip's passive-detect state
    // can wedge silently after RF/Vcc transients with no observable
    // symptom from outside — getFirmwareVersion still works, only
    // readPassiveTargetID stops returning hits. Two I2C transactions per
    // 5 s is cheap; doing this unconditionally covers both the
    // post-scan wedge and the boot wedge (chip flaky from cold start).
    if (nfcReady && fw != 0) nfc.rearm();
  }

  delay(10);
}

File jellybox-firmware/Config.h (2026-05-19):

#pragma once

// ── Firmware version ──────────────────────────────────────────────────────
// Injected at build time via -DFIRMWARE_VERSION="vX.Y.Z" by the release
// workflow. Falls back to "dev" for local Arduino IDE builds.
#ifndef FIRMWARE_VERSION
#define FIRMWARE_VERSION "dev"
#endif

// ── Hardware SKU ──────────────────────────────────────────────────────────
// Identifies the hardware variant this build targets. Injected at build time
// via -DJELLYBOX_SKU="jb-...-vN" by the release workflow's matrix. Devices
// report this to the server so it can offer the right OTA build and tell
// hardware variants apart on the dashboard. See apps/server/src/lib/skus.ts
// for the canonical registry.
#ifndef JELLYBOX_SKU
#define JELLYBOX_SKU "jb-eink-v1"
#endif

// ── Per-SKU capability flags ──────────────────────────────────────────────
// JELLYBOX_SKU is a string at compile time, which can't be used in #if
// directly. CI passes a matching numeric guard (e.g. -DJELLYBOX_SKU_TFT_V1)
// alongside the SKU string; this block expands that into capability flags
// the rest of the firmware #ifdefs on. Adding a future SKU means adding a
// branch here, not sprinkling SKU strings through the codebase.
#if defined(JELLYBOX_SKU_TFT_V1)
  #define JELLYBOX_DISPLAY_TFT      1
  #define JELLYBOX_HAS_AUDIO        1
  #define JELLYBOX_HAS_VOLUME_DIAL  1
#else
  // Default: jb-eink-v1
  #define JELLYBOX_DISPLAY_EINK     1
#endif

// ── Pin definitions ───────────────────────────────────────────────────────

// NeoPixel ring
#define PIN_NEOPIXEL    27
#define NEOPIXEL_COUNT  16

// PN532 NFC reader (I2C — SDA=21, SCL=22 are ESP32 defaults)
#define PIN_PN532_IRQ   25
#define PIN_PN532_RST   26

#ifdef JELLYBOX_DISPLAY_EINK
// eInk display (SPI — change to match your wiring)
// Defaults for Waveshare 2.9" V2 on common ESP32 dev boards
#define PIN_EINK_CS     5   // GPIO5 is an ESP32 strapping pin; CS idles HIGH so boot is unaffected
#define PIN_EINK_DC     17
#define PIN_EINK_RST    16
#define PIN_EINK_BUSY   4
#endif

#ifdef JELLYBOX_DISPLAY_TFT
// ST7789 colour TFT (SPI — shared VSPI MOSI=23/SCK=18). Reuses the freed
// eInk GPIO assignments so the same board layout works for both SKUs.
#define PIN_TFT_CS      5
#define PIN_TFT_DC      17
#define PIN_TFT_RST     16
#define TFT_W           320
#define TFT_H           240
#endif

#ifdef JELLYBOX_HAS_AUDIO
// MAX98357A I2S amplifier. Non-strapping pins; BCLK and LRC must be
// PWM-capable outputs, DIN is a regular GPIO.
#define PIN_I2S_BCLK    14
#define PIN_I2S_LRC     33
#define PIN_I2S_DIN     32
#define I2S_SAMPLE_RATE 16000   // 16 kHz mono — plenty for short cues
#endif

#ifdef JELLYBOX_HAS_VOLUME_DIAL
// KY-040 rotary encoder. ESP32 input-only pins (34/35/39) are fine — the
// encoder breakout has onboard pull-ups, so internal pull-ups aren't needed.
#define PIN_ENC_CLK     35
#define PIN_ENC_DT      34
#define PIN_ENC_SW      39      // press-button (reserved; not wired in v1)
#define NVS_KEY_VOLUME  "volume"
#define VOLUME_MAX      16      // step scale (matches NEOPIXEL_COUNT)
#define VOLUME_DEFAULT  12
#endif

// BOOT/GPIO0 button — hold on power-up to factory reset
#define PIN_FACTORY_RESET 0

// ── WiFi / captive portal ─────────────────────────────────────────────────
#define WIFI_AP_NAME        "Jellybox-Setup"
#define WIFI_AP_PASSWORD    ""          // open AP
#define WIFI_TIMEOUT_S      180         // seconds before config portal times out

// ── NVS storage ───────────────────────────────────────────────────────────
#define NVS_NAMESPACE   "jellybox"
#define NVS_KEY_SERVER  "serverUrl"
#define NVS_KEY_APIKEY  "apiKey"

// ── Timing ────────────────────────────────────────────────────────────────
#define BOOTSTRAP_INTERVAL_MS  30000UL  // poll /api/device/me every 30 s
#define SCAN_DEBOUNCE_MS       15000UL  // ignore same UID for 15 s
#define FACTORY_RESET_HOLD_MS   3000UL  // hold BOOT 3 s → factory reset
#define LED_UPDATE_INTERVAL_MS    20UL  // ~50 fps LED refresh
#define HEARTBEAT_INTERVAL_MS   5000UL  // UDP diagnostic heartbeat cadence

// ── UDP debug logging ─────────────────────────────────────────────────────
// Fire-and-forget logs to any machine on the LAN. Listen with:
//   nc -u -l 5514
//   socat -u UDP-LISTEN:5514,fork - | ts   (preferred — adds timestamps)
// Override UDP_LOG_HOST to a specific IP if your AP filters broadcast.
#define UDP_LOG_HOST   "255.255.255.255"
#define UDP_LOG_PORT   5514

// ── Device config (loaded from NVS) ───────────────────────────────────────
struct DeviceConfig {
  String serverUrl;  // e.g. "https://jellybox.example.com"  (no trailing slash)
  String apiKey;     // e.g. "jb_abc123..."
};

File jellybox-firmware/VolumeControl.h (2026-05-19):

#pragma once

// ── KY-040 rotary encoder volume dial ─────────────────────────────────────
// Polls the quadrature encoder in the main loop. Each detent steps the
// volume by 1 unit in the 0..VOLUME_MAX range. Level is persisted to NVS
// with a 500 ms idle debounce so we don't thrash flash on a long spin.
//
// The state machine is the classic 4-state Gray-code lookup that filters
// bounce: only +1 or -1 transitions in the table are real detents; all
// other AB pairings are noise and ignored.
//
// SW (press) is read on PIN_ENC_SW but not acted on in v1 — the pin is
// reserved for a future mute toggle.

#include <Arduino.h>
#include <Preferences.h>
#include "Config.h"

class VolumeControl {
public:
  void begin() {
    pinMode(PIN_ENC_CLK, INPUT);
    pinMode(PIN_ENC_DT,  INPUT);
    pinMode(PIN_ENC_SW,  INPUT);

    Preferences prefs;
    prefs.begin(NVS_NAMESPACE, true);
    _level = prefs.getUChar(NVS_KEY_VOLUME, VOLUME_DEFAULT);
    prefs.end();
    if (_level > VOLUME_MAX) _level = VOLUME_DEFAULT;

    _lastAB  = _readAB();
    _persisted = _level;
    _dirtyAt = 0;
  }

  // Call every loop iteration. Non-blocking, typically < 50 µs.
  void update() {
    uint8_t ab = _readAB();
    if (ab != _lastAB) {
      // Quadrature transition table indexed by (prev<<2 | curr).
      //   0  =  no change / illegal
      //  +1  =  CW detent
      //  -1  =  CCW detent
      static const int8_t kTable[16] = {
        0, -1, +1,  0,
        +1,  0,  0, -1,
        -1,  0,  0, +1,
        0, +1, -1,  0,
      };
      int8_t delta = kTable[(_lastAB << 2) | ab];
      _lastAB = ab;
      if (delta != 0) {
        // KY-040 emits 4 transitions per physical detent; only count
        // when AB returns to the rest position (0b11) for a clean step.
        if (ab == 0b11) {
          if (delta > 0 && _level < VOLUME_MAX) _level++;
          if (delta < 0 && _level > 0)          _level--;
          _dirtyAt = millis();
        }
      }
    }

    // Debounced persist: 500 ms after the last change, write to NVS.
    if (_dirtyAt && (millis() - _dirtyAt) > 500 && _level != _persisted) {
      Preferences prefs;
      prefs.begin(NVS_NAMESPACE, false);
      prefs.putUChar(NVS_KEY_VOLUME, _level);
      prefs.end();
      _persisted = _level;
      _dirtyAt = 0;
    }
  }

  uint8_t level() const { return _level; }

  // 0.0 – 1.0 amplitude scale, ready to hand to AudioFeedback.
  float gain() const {
    return (float)_level / (float)VOLUME_MAX;
  }

private:
  uint8_t _level    = VOLUME_DEFAULT;
  uint8_t _persisted = VOLUME_DEFAULT;
  uint8_t _lastAB    = 0b11;
  uint32_t _dirtyAt   = 0;

  // Returns the 2-bit AB state. Pull-ups are external (on the breakout),
  // so the resting state is 0b11.
  uint8_t _readAB() const {
    uint8_t a = digitalRead(PIN_ENC_CLK) ? 1 : 0;
    uint8_t b = digitalRead(PIN_ENC_DT)  ? 1 : 0;
    return (uint8_t)((a << 1) | b);
  }
};

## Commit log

2026-04-15 Initial Box Models
    [Jellybox Case.stl, Jellybox Lid.stl]
2026-04-15 Update Case
    [Jellybox Case.stl]
2026-04-16 New Jellybox Case
    [Jellybox Case.stl]
2026-04-17 Jellybox Case
    [Jellybox Case.stl]
2026-04-21 Idle screen rework and doc fixes
    - showReady: drop "Ready to scan" (eInk persists after power-off and
    would lie); show centred logo with device name instead.
    - Fix NeoPixel count in docs (12 → 16) to match Config.h.
    - Reconcile EINK_MARGIN_R comment with actual value.
    - Add CLAUDE.md with architecture notes for future sessions.
2026-04-26 Next Iteration of STL
    [Jellybox Case.stl, Jellybox Lid.stl]
2026-04-30 New Case Revision
    [Jellybox Case.stl]
2026-05-04 docs: document OTA flow in README
    Adds an Over-the-Air Updates section covering the release pipeline,
    rollback safety, dev-build behaviour, and partition-scheme requirement.
    Updates LED state, eInk screen, file structure, state machine, API
    response, and serial monitor sections to reflect the OTA additions.
2026-05-04 trim: drop captive-portal CSS and charge-detection LED feedback
2026-05-05 Re-start NFC after scan, fix ring colours
    [jellybox-firmware.ino]
2026-05-05 debug: log bootstrap key + latestFirmware, silence eInk pinMode warnings
    Pre-pinMode the eInk CS/DC/RST pins so GxEPD2's init() doesn't trip
    the ESP32 core 3.x "digitalWrite before pinMode" runtime check.
    [jellybox-firmware.ino]
2026-05-18 re arm nfc
2026-05-18 nfc: inRelease before SAMConfig, preemptive rearm in heartbeat
    SAMConfig alone leaves the library's _inListedTag flag set, so
    subsequent readPassiveTargetID short-circuits and returns false
    even though the chip is fine. Pair every SAMConfig with inRelease.
    Also rearm every heartbeat so a silent wedge recovers within ~5s
    instead of needing a reset.
    [jellybox-firmware.ino]
2026-05-18 nfc: drop inRelease — not in Adafruit_PN532 v1.3.0
    v0.0.13 failed CI because inRelease() isn't exposed in the pinned
    library version. The _inListedTag flag it would clear is only set
    when readPassiveTargetID is called with inlist=true, which we
    don't do — so the calls weren't load-bearing anyway. The heartbeat
    preemptive SAMConfig (every 5s) plus the post-bootstrap and
    post-handleScan rearms are the real new defenses.
2026-05-20 Update 3D Models
    [Jellybox Case.stl, Jellybox Logo.stl, Jellybox Ring.stl]
